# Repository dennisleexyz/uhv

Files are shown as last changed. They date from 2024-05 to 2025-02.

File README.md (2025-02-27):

# Unmanned Hybrid Vehicle (UHV)

California State Polytechnic University, Pomona (Cal Poly Pomona, CPP)\
College of Engineering\
Department of Electrical and Computer Engineering (ECE Department)

The Unmanned Hybrid Vehicle (UHV) combines a drone (Unmanned Aerial Vehicle; UAV) and rover (Unmanned Ground Vehicle; UGV). See the design review papers (PDF documents) for more information.

I unfortunately don't have any other files to share. If you're a team member, check/ask on Discord, and I encourage you to fork this repository to add stuff.

This was my undergraduate senior design project (under the name Flying UGV, or "Gliese-514b") with the Reconfigurable Space Computing Lab (RSCL) led by Professor Mohamed El-Hadedy Aly. We were selected by the [NASA MINDS](https://www.nasa.gov/learning-resources/minority-university-research-education-project/nasa-minds/) competition for Artemis mission research. I worked on it from Fall 2023 to Spring 2024 alongside the following team members:

- Manuel Tarula-Villareal
- Javier Eguia Chaire
- Ruben Torres Romero
- Justin Villamil

Students have rotated in and out as the project has continued since then.

If I'm not allowed to share anything here, contact me to have it taken down. All rights reserved.

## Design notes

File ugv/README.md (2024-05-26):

# UGV

Unmanned Ground Vehicle

## Hardware Setup

The UGV motors are controlled by an L298N Dual H-Bridge Driver connected to a Raspberry Pi.

Raspberry Pi is normally USB powered but can also be powered over GPIO power pins (+5V/Ground). This bypasses power protection circuitry for unstable supplies, but the Pixhawk provides regulated 5V pins. This provides enough power for headless operation. In the event that a monitor is needed, it will draw too much power and shut off; unplug the +5V supply pin and plug in USB power (don't connect both at the same time). If using the signals, ensure that the ground pin remains connected to the Pixhawk in order to provide a common ground with the L298N or else they will not work.

We should measure the current draw by the Pi from the Pixhawk under load to see what the maximum is before shut off. In the future we should try tapping 5V directly from the power module to see if this will allow for more current.

Pi 4 and up are annoying because of the switch to mini-HDMI port, for which cables are not as readily available. For this reason, consider going back to Pi 3 if the extra compute power is not needed.

### Wiring Diagram

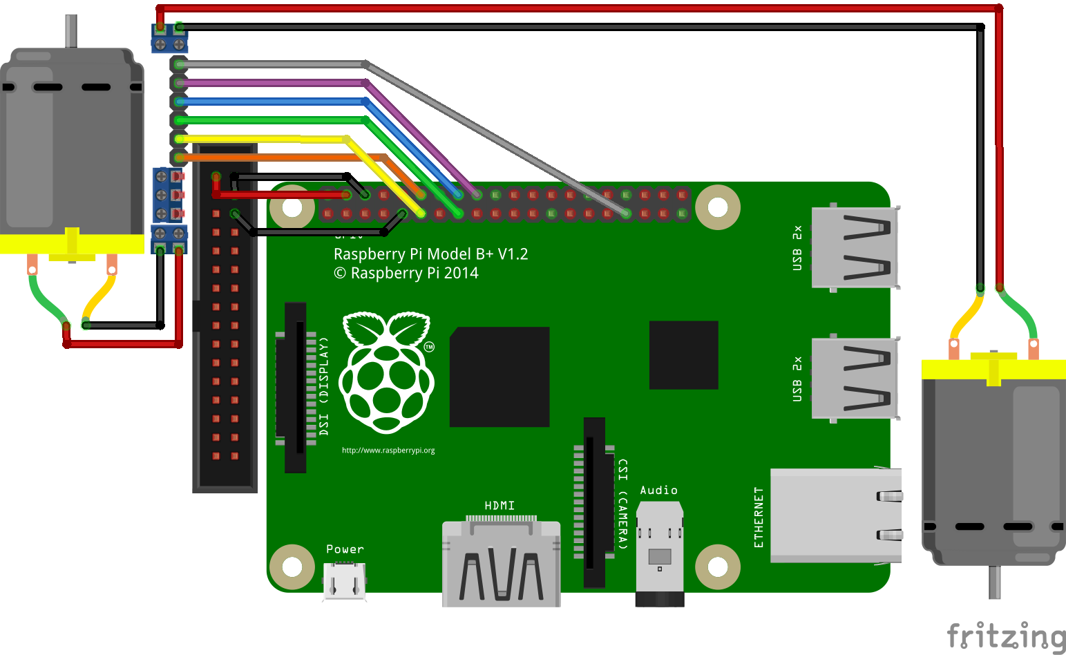
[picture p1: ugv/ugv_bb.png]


The wiring diagram was made in [Fritzing](https://fritzing.org/). The source file is included in this repository so you can edit it if needed. Fritzing will also show you what the pins are on the Pi when you hover over them in the program.

Pi GPIO pin reference: https://pinout.xyz/

Different GPIO pins can be used; just adjust the code accordingly.

The top row of pins on the Pixhawk is ground; the middle row is 5V. See https://ardupilot.org/copter/docs/common-pixhawk-overview.html

## Software Setup

For wireless communication we connect to the Pi over eduroam using SSH.

The password is not your normal password that you use to log in to your MyCPP portal. Rather it is a separate network password that you can set by going to https://apps.cpp.edu/

To enable incoming SSH connections on the Pi, open Preferences > Raspberry Pi Configuration. Go to the Interfaces tab. Ensure the SSH radio button is set to Enable and click OK.

On the Pi, run
```sh
hostname -I
```
to determine its IP address, which looks something like this.
```
10.110.xxx.xxx
```
Use this for the following steps.

On your computer, run
```sh
ssh pi@10.110.xxx.xxx
```
to connect to the Pi.

Get the code on the Pi, either by cloning this repository
```sh
git clone https://github.com/dennisleexyz/uhv
cd uhv/ugv
```
or just copying it over from your local machine
```sh
scp ugv.py pi@10.110.xxx.xxx:
```

Run it
```sh
python3 ugv.py
```

`WASD` is Up/Left/Down/Right, `J` and `K` to lower and raise PWM duty cycle respectively to the motors. Warning: duty cycle starts at full speed by default.

The IP address is not stable, it is subject to change periodically. Expect that you will need to re-acquire it.

### Raspbian

Raspbian's UI for connecting to a network does not support WPA Enterprise networks, e.g. eduroam. We can install NetworkManager and use that instead, disabling the default.

```sh
sudo apt install network-manager{,-gnome}
sudo systemctl disable --now dhcpcd
sudo systemctl enable --now network-manager
setsid nm-applet
```

See https://raspberrypi.stackexchange.com/a/119653

# Troubleshooting

The battery connector may need to be replaced e.g. in the event that the battery is plugged in backwards (reverse polarity). When replacing the connector, care will need to be taken to ensure that the two terminals do not short. Use the yellow XT90 connectors, which are on all of the batteries in the lab and not prone to being plugged in backwards like the blue connectors.

Cut the wire directly underneath just one of the connector terminals, using a sufficiently small wire cutter to prevent sparking with the other terminal. Place the connector sleeve on the wire. Strip and solder the wire to the correct solder cup (ensure the same polarity) on the new connector. Ensure continuity between the inside connector terminal and the solder (not the cup) using a multimeter. Insulate the new solder joint with Kapton tape. Now cut the wire directly underneath the old connector on the other terminal. Ensure the connector sleeve is on both wires before stripping and soldering the second wire, or you will have to desolder to put it on. After soldering the second wire and testing continuity, push the sleeve onto the new connector. You may have to remove the Kapton tape first.

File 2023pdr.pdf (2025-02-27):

## Development of Aerial Unmanned Ground Vehicles (UGV) to Enhance Support for the ARTEMIS Lunar Mission

## Gliese-514b

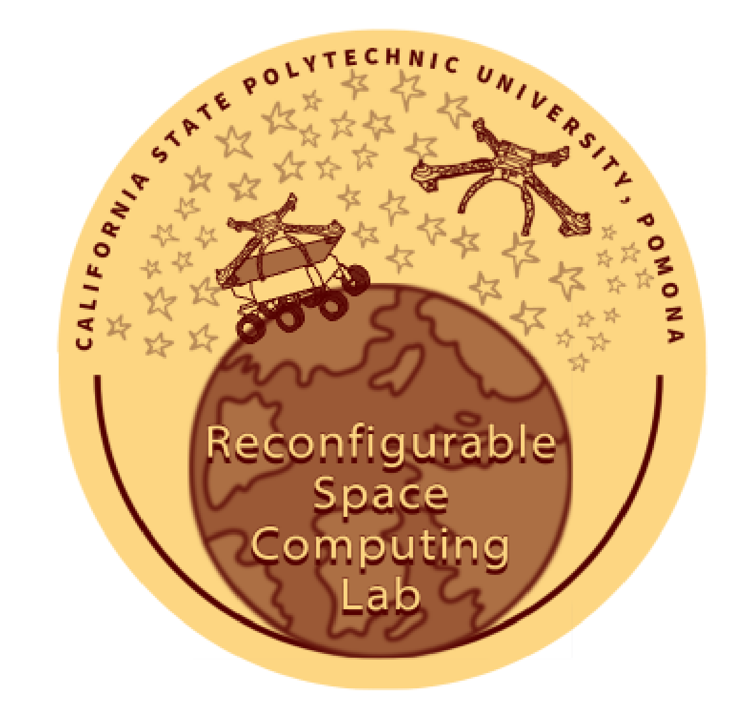
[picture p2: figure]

Team Members:
Ruben Torres Romero, Manuel Tarula, Dennis Lee

Faculty Advisor: Professor: Mohamed El-Hadedy Aly

Email:mealy@cpp.edu

California State Polytechnic University, Pomona Department of Electrical and Computer Engineering, College of Engineering

X

Signature of the sponsoring faculty advisor verifying that he has read and reviewed the paper prior to submission to NASA.

CONTENTS

I | Executive Summary | 1
II | Initial Project Schedule | 1
III | Budget Justification | 1
IV | Research | 2
I | Relevant Background | | 2
II | Problem Statement | | 3
a | Revolutionizing Lunar Exploration: Team Gliese-514b’s Innovative
Approach | | 3
III | Innovations | | 3
a | Technological Innovations: | | 4
IV | ARTEMIS Mission | | 4
V | Technical | 4
I | Gliese-514b team | | 4
II | Project Plan | | 4
III | Software Plan | | 5
Appendix A: Gantt Chart | 7
Appendix B: Cost Breakdown | 7

# Development of Aerial Unmanned Ground Vehicles (UGV) to Enhance Support for the ARTEMIS Lunar Mission

I. EXECUTIVE SUMMARY
Team Gliese-514b introduces a groundbreaking Aerial Unmanned Ground Vehicle (AUGV) tailored for the ARTEMIS Lunar Mission. Our AUGV is designed to navigate the moon’s challenging terrains, merging aerial and terrestrial capabilities for optimal exploration. Pioneering a unique approach, we utilize reconfigurable computing platforms to calculate real-time energy consumption during mode transitions. This innovative solution ensures efficient energy use, enabling extended operational duration. Our renewed team composition, with diverse expertise, commits to bridging the technological gaps in lunar exploration, enhancing mission success potential, and charting a path for future interplanetary endeavors.

II. INITIAL PROJECT SCHEDULE
The Gantt chart presented in Appendix A offers a comprehensive overview of Gliese-514b’s meticulous project plan. The endeavor unfolds through three distinct phases, each marked by specific objectives and actions, meticulously structured for success:
- Phase 1: Research and Design In the initial phase, Gliese-514b embarks on an exhaustive exploration of mechanical design possibilities for the Flying UGV. This encompasses the creation of a detailed 3D model and the meticulous specification of essential components crucial for enabling both ground and aerial navigation. Simultaneously, a dedicated software development effort is set in motion to orchestrate the seamless orchestration of sensors and flight control systems.
- Phase 2: Assembly and Hardware Implementation The second phase witnesses Gliese-514b’s procurement efforts as they acquire every essential hardware component required for the assembly of the Flying UGV. Furthermore, this stage is marked by the intricate integration of various peripherals, harmoniously weaving them into the fabric of the UGV. A symphony of components comes to life as they are meticulously assembled and brought together.
- Phase 3: Testing and Implementation The final leg of the journey ushers in rigorous testing and implementation efforts. Gliese-514b meticulously subjects the assembled UGV to a battery of tests, scrutinizing its performance in both ground and flight modes. This phase serves as the crucible in which the Flying UGV’s capabilities are benchmarked, and refinements to the design are deftly implemented. It is the culmination of the team’s efforts, where the vision becomes a tangible reality. In these meticulously structured phases, Gliese-514b’s mission unfolds, propelled by dedication, precision, and an unwavering commitment to achieving its objectives.

III. BUDGET JUSTIFICATION

Appendix B provides a comprehensive breakdown of the materials and associated costs crucial for the realization of the Gliese-514b project. Each component and resource has been carefully selected to align with the project’s objectives, with an unwavering focus on efficiency and functionality.
The backbone of the Gliese-514b Flying UGV is its chassis, a critical component known for its remarkable strength, durability, and ease of fabrication. To this end, the chassis will be precisioncut from acrylic, ensuring a solid foundation for the UGV’s operations. Additionally, PLA filament will be skillfully employed to craft miscellaneous parts, enhancing the overall versatility and functionality of the Flying UGV.
Powering the UGV’s electrical systems will be battery units, affording the flexibility and mobility necessary for its mission. The central nervous system of the UGV comprises a Raspberry Pi, complemented by a Navio2 HAT. An intricate network of wires serves as the neural pathways connecting various components, facilitating seamless coordination and control.
The UGV’s locomotion is driven by a combination of four propellers and four wheels, each meticulously powered by dedicated motors. Two sets of 4 in 1 ESCs [1] provide the precise motor control required for optimal performance. Notably, the choice of motors for the wheels prioritizes higher torque and lower RPM, a deliberate decision to meet the UGV’s specific operational demands. Communication lies at the heart of the Gliese-514b project, necessitating the integration of a telemetry radio system to maintain a robust connection between the UGV and the ground control station.
Navigation | and | mapping | capabilities | are
paramount | for | the | UGV, | achieved | through
the inclusion of camera sensors [2] and a LiDAR sensor. While the Raspberry Pi inherently supports a single camera, Gliese-514b’s multifaceted approach mandates the use of a camera port multiplexer to transcend this limitation. Furthermore, high-power infrared LEDs are enlisted to enhance visibility in low-light environments, ensuring the UGV’s adaptability to various scenarios.
Lastly, an SSD storage solution accommodates the substantial volume of data generated by the Li-DAR sensor and multiple cameras [3]. This storage capacity ensures that critical data can be efficiently captured, stored, and utilized throughout the mission.
In sum, Gliese-514b’s material and cost allocation exemplify a meticulous selection process, guided by the team’s unwavering commitment to achieving project success through precision, efficiency, and optimal functionality.

IV. RESEARCH

A. Relevant Background
The Artemis mission unfolds in three distinct phases, each marking a significant milestone in humanity’s journey into space. Artemis I marked a pivotal moment with NASA successfully launching the Orion Spacecraft. This mission also involved the comprehensive development and testing of essential elements such as the space launch system rocket, the human landing system, and the exploration ground systems. Rigorous testing was conducted to finetune these critical utilities, ensuring their readiness for the challenges that lie ahead.
Artemis II stands as the next ambitious endeavor, set to send astronauts to the Moon in 2025, with the ultimate goal of establishing a lunar base. This mission aims to further test the endurance of astronauts, the reliability of the Orion Spacecraft, the space launch system rocket, the human landing system, and the exploration ground systems. It’s a critical step toward building operational confidence and preparing for Artemis III.
Artemis III represents the pinnacle of ambition, envisioning the establishment of a lunar base that will serve as a launchpad for Mars exploration. The Moon will become a hub for scientific research and technological advancement, acting as a stepping stone toward the grander goal of Mars exploration. This mission heralds an era where a minimal human presence interacts with advanced technology, all for the betterment of humanity.
However, lunar exploration presents formidable challenges, particularly in the challenging terrain of the Moon’s far side. Traditional rovers struggle to navigate uneven and rugged landscapes, highlighting a technological gap in our ability to explore efficiently. The need for swift and adaptable aerial and terrestrial navigation in these harsh conditions is evident, promising to revolutionize lunar exploration and enhance data collection.
In response to this challenge, team Gliese-514b rises to the occasion with a groundbreaking proposal—an innovative Aerial Unmanned Ground Vehicle (AUGV). This visionary creation combines the strengths of flight-capable drones and ground-based rovers, offering unparalleled agility to soar over treacherous terrains and the stability to maneuver on the ground when required.
Gliese-514b’s AUGV is set to redefine lunar exploration, bridging the gap between aerial and terrestrial capabilities. It promises to revolutionize the efficiency, range, and speed of lunar missions, enabling comprehensive data collection and significantly increasing the probability of mission success. With this innovative solution, the team paves the way for a new era of lunar exploration, unlocking the mysteries of our celestial neighbor and propelling humanity toward the stars.

B. Problem Statement

The Gliese-514b team is tackling a pressing challenge in lunar exploration—bridging the technological gap for more efficient and adaptable surface exploration. Currently, the Artemis program relies heavily on orbital surveys, providing only a limited understanding of lunar landing sites. The moon’s rugged terrain, marked by craters and steep slopes, presents significant challenges for traditional Unmanned Ground Vehicles (UGVs), hindering efficient surface exploration. To overcome these obstacles and enhance mission planning, the team proposes the integration of a Flying Unmanned Ground Vehicle (AUGV) with the capability to conduct detailed lunar surface surveys.
This innovative approach aims to revolutionize lunar exploration by providing a versatile solution that seamlessly transitions between aerial and terrestrial modes. The AUGV’s robust propulsion system, combined with specialized wheel or track systems, enables it to , conserving energy and overcoming large obstacles. Furthermore, the team’s focus on energy consumption calculation using reconfigurable computing platforms ensures real-time feedback on the AUGV’s energy status, contributing to longer mission durations and enhanced exploration capabilities.
1) Revolutionizing Lunar Exploration: Team Gliese-514b’s Innovative Approach: Team Gliese-514b distinguishes itself through its multidisciplinary expertise and holistic project approach. Bringing together diverse skills in aerospace dynamics, robotics, computational intelligence, and reconfigurable computing platforms, the team ensures a comprehensive solution to the problem. Their emphasis on energy consumption calculation using reconfigurable computing platforms not only benefits the current project but also paves the way for adaptable, energy-efficient systems in future lunar missions.
In conclusion, the Aerial-Terrestrial UGV proposed by team Gliese-514b addresses a critical technological gap in lunar exploration [4]. By merging aerial and terrestrial navigation capabilities, their innovative solution promises to navigate the challenging lunar terrain efficiently and adaptable. This contribution has the potential to significantly enhance the success of future lunar missions within the NASA Artemis program, optimizing unmanned lunar exploration for strategic mission planning and safe lunar surface activities.
C. Innovations

The Gliese-514b project is dedicated to the creation of a low-power, low-latency Flying Unmanned Ground Vehicle (UGV) tailored for versatile applications, with a particular focus on its role during the Artemis III mission phase. Operating under the umbrella of the Reconfigurable Space Computing Laboratory at CPP, Gliese-514b is an integral part of a pioneering initiative aimed at developing cuttingedge technology to establish a collaborative robotic environment as shown in Figure 1. This environment facilitates the seamless coordination of heterogeneous robotic elements for deep-space missions, effectively executing tasks and transmitting critical data to Earth for further analysis, as illustrated in Figure 1.
The project’s core objectives revolve around the comprehensive development of both software and hardware platforms, culminating in the creation of a robust and fully integrated system optimized for lunar and Mars exploration. The overarching vision envisions the deployment of this innovative device within a collaborative robotics framework, significantly enhancing the efficiency and adaptability of exploration endeavors.
At the heart of this endeavor lies a resilient propulsion system capable of facilitating smooth transitions between flying and driving modes. This pioneering propulsion technology not only promises to deliver higher-resolution scans of the lunar surface but also positions the Flying UGV as an indispensable asset for lunar and Martian exploration missions. Furthermore, the incorporation of LiDAR sensors enhances the vehicle’s navigational capabilities, allowing real-time mode adjustments based on the prevailing environmental conditions.
In tandem with the adaptable propulsion system, the Gliese-514b team is actively engaged in the development of a specialized algorithm, leveraging the potential of reconfigurable computing platforms. This algorithm serves a critical role in meticulously calculating energy consumption during transitions between flying and driving modes, providing real-time energy analysis crucial for mission planning. This ensures that the Flying UGV operates efficiently within predefined energy thresholds, opti-

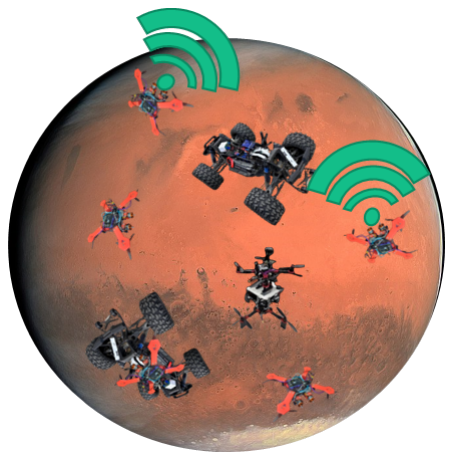
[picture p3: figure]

Fig. 1: Collaborative Robotic Environment featuring the Gliese-514b Flying UGV

mizing resource utilization in the demanding lunar environment.
1) Technological Innovations::
- Flying-to-Driving Transition: The AUGV boasts a robust propulsion system capable of stable hovering and dynamic flying maneuvers. Coupled with specialized wheel or track systems, this system enables seamless transitions between flight and ground modes. Such versatility ensures that the AUGV can surmount obstacles by flying and continuing its journey on the ground, optimizing energy conservation.
- Energy Consumption Calculation: Efficient energy utilization is a fundamental challenge for multi-modal vehicles. The Gliese-514b project addresses this challenge by developing a specialized algorithm on a reconfigurable computing platform to accurately compute power consumption during transitions between flying and driving modes. Real-time energy analysis aids in mission planning, ensuring that the AUGV always operates within safe energy thresholds.
- Terrain Adaptability: To navigate the capricious lunar terrain, the AUGV incorporates advanced terrain sensing capabilities. These sensors provide real-time feedback to the system, enabling it to determine the optimal mode of movement, whether flight or ground-based, depending on the prevailing environmental conditions.
D. ARTEMIS Mission
Team Gliese-514b’s Aerial Unmanned Ground Vehicle (AUGV) plays a pivotal role in bolstering

NASA’s ARTEMIS Lunar Mission by significantly enhancing navigation capabilities across the moon’s formidable terrains. By seamlessly integrating both aerial and terrestrial functionalities, the AUGV enables efficient and comprehensive exploration, particularly on the rugged and challenging dark side of the moon. Moreover, the Gliese-514b Flying UGV offers invaluable support to the Artemis Mission through its advanced navigation and terrain mapping capabilities. Equipped with LiDAR sensors, it adeptly navigates the unpredictable lunar terrain, effortlessly switching between ground and flight modes, ensuring unparalleled mobility, and generating detailed maps of the rugged lunar landscape. This multifaceted approach empowers the mission with enhanced adaptability and data collection capabilities.

V. TECHNICAL
A. Gliese-514b team

The current project is centered on setting up equipment on a flexible resin-printed chassis, aiming to enhance computational capabilities with a customized flight controller based on the F’ JPL/NASA flight software. This setup includes a thermal camera for chip monitoring. Future work will focus on predicting chip failure due to intensive activities.

B. Project Plan

To initiate the Flying UGV project, the primary step involves conceiving a lightweight chassis design with a minimal footprint, as illustrated in Figure 3. This updated design seamlessly accommodates all essential components required for autonomous flight, driving, and exploration, representing an improvement over the previous design showcased in Figure 2. The new design features a more robustly engineered, lightweight chassis, which will be fabricated using either laser-cut acrylic or light resin [5], with ongoing investigations to determine the ideal material for the final prototype. Once the dimensions and optimal arrangement of these components are determined, the subsequent phase involves the development of a comprehensive 3D CAD model. The chassis, as depicted in Figure 2, will be crafted from acrylic and complemented with 3D printed components. Following the fabrication of

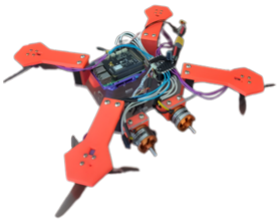
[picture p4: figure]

Fig. 2: Flying UGV Prototype of Past Design

these components, the assembly of the Flying UGV can commence.
Simultaneously, while finalizing the physical design, the software aspect of the project will be actively worked on. Team Gliese-514b will begin establishing communication protocols with the various cameras, sensors, and ESCs to ensure seamless integration and operation.
Upon the successful assembly and the establishment of seamless communication with its components, Gliese-514b will proceed to conduct a series of rigorous tests on the Flying UGV. The testing phase will commence with remote operation trials, subsequently followed by autonomous navigation testing in both ground and flight modes.
C. Software Plan
The software stack chosen for this project encompasses several key components to enable the Flying UGV’s comprehensive exploration and mapping capabilities. It includes the PiCamera app for PiCameras, DroidCam for the potential addition of another camera through a smartphone, and LidarView to process data from the LiDAR sensor. The aim is to leverage multiple image and videoproducing devices to conduct thorough scans and assess the lunar or Martian surroundings, ultimately creating detailed maps. Additionally, the LiDAR and camera inputs will facilitate the extraction of positioning information, enabling the system to calculate potential obstacles and its relative position within the observed area. The software will play

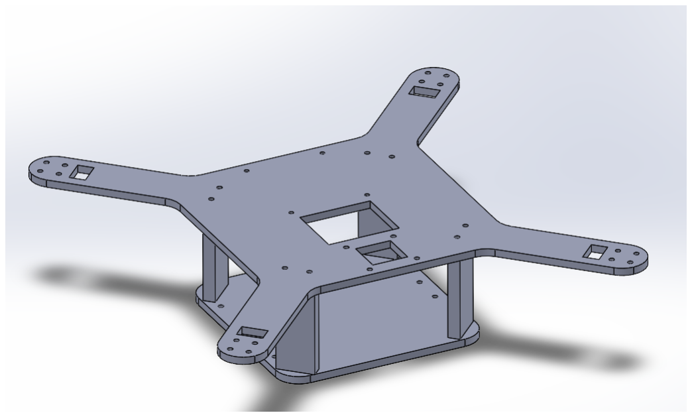
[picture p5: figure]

Fig. 3: CAD of Current Drone

a crucial role in associating the surroundings with precise coordinate references, enhancing the overall mapping process.
To enhance the Flying UGV’s ability to differentiate between various materials and objects found on the Moon, computer vision capabilities will be integrated. This involves training a YOLOv8 model on cloud resources to enable the identification of different vehicles and objects [6]. Initial simulations will be conducted on Earth-based devices and objects to validate the proof of concept. The long-term vision is to train and deploy a model within the UGV itself, allowing it to avoid collisions with counterparts during missions. Additionally, teleoperation features will be added to the Flying UGV, utilizing the MediaPipe Library and potentially YOLOv8. Hand gestures will serve as the means to convey start and stop commands to the UGV, enhancing its control and interaction capabilities.
Following the creation and full integration of the software stack, Gliese-514b will proceed with rigorous testing procedures. Successful tests will pave the way for the software’s utilization of the actual drones. This entails the establishment of boundary conditions, such as ensuring the Flying UGV maintains a safe distance of 1 meter from obstacles. The computer vision aspect will enable task assignment and control, making the project safe and collision-free. Moreover, it will provide astronauts with a means to assign tasks to the UGV, fostering a collaborative robotic environment where the device can receive instructions through gestures or local networks from other similar vehicles.

REFERENCES
[1] B.-S. Jun, Y.-S. Kook, J.-S. Park, and C.-Y. Won, “A development of electronic speed control (esc) for pmsms driving used in drone,” in 2018 IEEE International Power Electronics and Application Conference and Exposition (PEAC), 2018, pp. 1–4. DOI

: 10.1109/PEAC.
2018.8590355 (https://doi.org/10.1109/PEAC.2018.8590355)
[2] A. A. Sarawade and N. N. Charniya, “Infrared thermography and its applications: A review,” in 2018 3rd International Conference on Communication and Electronics Systems (ICCES), 2018, pp. 280–285. DOI
: 10 . 1109 / CESYS .
2018.8723875 (https://doi.org/10.1109/CESYS.2018.8723875)
[3] Y. J. Hao, L. K. Teck, C. Y. Xiang, E. Jeevanraj, and S. Srigrarom, “Fast drone detection using ssd and yolov3,” in 2021 21st International Conference on Control, Automation and Systems (ICCAS), 2021, pp. 1172–1179. DOI

:
10.23919/ICCAS52745.2021.9650015 (https://doi.org/10.23919/ICCAS52745.2021.9650015)
[4] L. Deng, B. Yang, X. Dong, et al., “Self-spin enabled docking and detaching of a uav-ugv system for aerial-terrestrial amphibious and independent locomotion,” IEEE Robotics and Automation Letters, vol. 8, no. 5, pp. 2454– 2461, 2023. DOI

: 10.1109/LRA.2023.3254445 (https://doi.org/10.1109/LRA.2023.3254445) .
[5] P. Gupta, M. Bhat, V. Khamkar, G. Tandel, and
G. Salunkhe, “Designing of cost effective resin 3d printer using uv led,” in 2020 International Conference on Convergence to Digital World
- Quo Vadis (ICCDW), 2020, pp. 1–4. DOI :
10.1109/ICCDW45521.2020.9318691 (https://doi.org/10.1109/ICCDW45521.2020.9318691)
[6] J.-H. Kim, N. Kim, and C. S. Won, “Highspeed drone detection based on yolo-v8,” in ICASSP 2023 - 2023 IEEE International Conference on Acoustics, Speech and Signal Processing (ICASSP), 2023, pp. 1–2. DOI: 10 . 1109/ICASSP49357.2023.10095516 (https://doi.org/10.1109/ICASSP49357.2023.10095516)

APPENDIX A
GANTT CHART

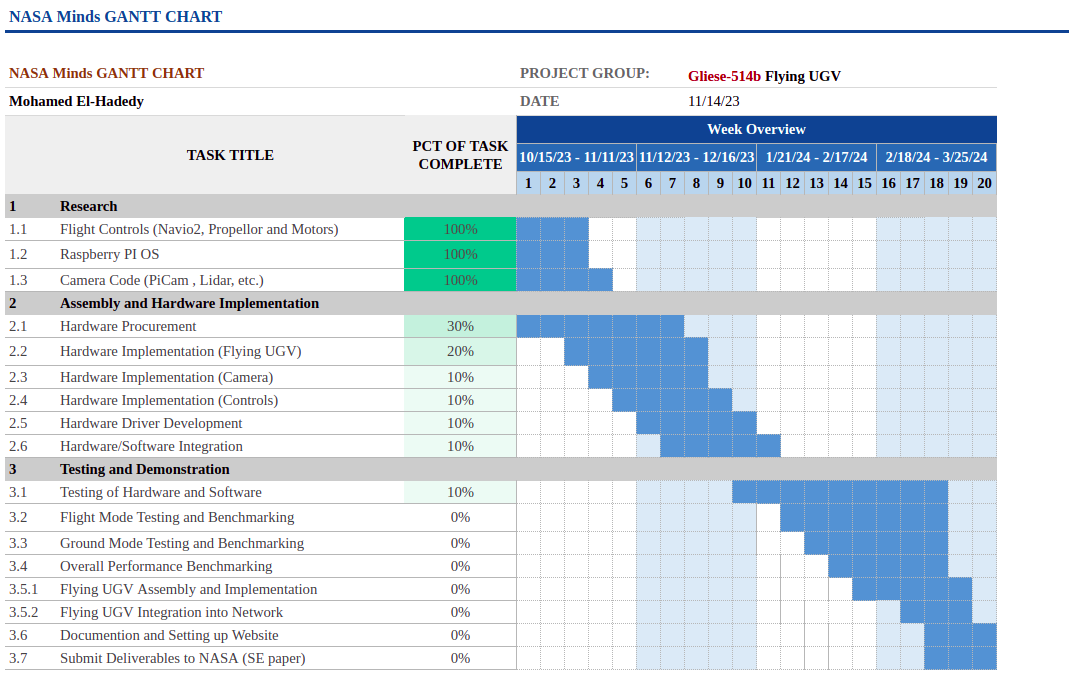
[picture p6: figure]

Gantt Chart of Scheduling

APPENDIX B
COST BREAKDOWN
Name | Cost ($) | Amount | Total Cost ($)
Acrylic sheets | 32.00 | 2 | 64.00
Raspberry Pi | 79.81 | 1 | 79.81
Navio2 Flight Controller | 100.00 | 1 | 100.00
Propeller Motors | 24.00 | 4 | 96.00
Wheel Motors | 34.00 | 4 | 136
ESC | 100.00 | 2 | 200.00
4s Battery | 80.00 | 1 | 80.00
Telemetry Radio | 90.00 | 1 | 90.00
Camera | 59.99 | 4 | 239.96
PLA Filament | 25.00 | 2 | 50.00
LiDAR Sensor | 54.00 | 1 | 54.00
Wheels | 8.25 | 4 | 33.00
Propellers | 10.00 | 4 | 40.00
Multicamera adapter | 29.99 | 1 | 29.99
Jumper wires | 19.98 | 1 | 19.98
Infrared LEDs | 8.99 | 4 | 35.96
2TB SSD | 159.99 | 1 | 159.99
Total | | | $1,508.69

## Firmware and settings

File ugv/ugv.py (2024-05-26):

#!/usr/bin/env python3

import RPi.GPIO as GPIO
from sshkeyboard import listen_keyboard
import time

# Setup
GPIO.setmode(GPIO.BCM)
GPIO.setwarnings(False)

# Motor A
ena = 18  # Motor A speed control
motorA_pin1 = 17
motorA_pin2 = 22

# Motor B
enb = 13  # Motor B speed control
motorB_pin1 = 24
motorB_pin2 = 23

# Setup the motor pins as outputs
GPIO.setup(ena, GPIO.OUT)
GPIO.setup(enb, GPIO.OUT)
GPIO.setup(motorA_pin1, GPIO.OUT)
GPIO.setup(motorA_pin2, GPIO.OUT)
GPIO.setup(motorB_pin1, GPIO.OUT)
GPIO.setup(motorB_pin2, GPIO.OUT)

# Initialize PWM
pwmA = GPIO.PWM(ena, 1000)  # Initialize PWM on ena 1000Hz frequency
pwmB = GPIO.PWM(enb, 1000)  # Initialize PWM on enb 1000Hz frequency

# Start PWM with a defined speed
speed = 100
pwmA.start(speed)  # Adjust this value between 0-100 to control speed
pwmB.start(speed)  # Adjust this value between 0-100 to control speed

def motors_forward():
    GPIO.output(motorA_pin1, GPIO.LOW)
    GPIO.output(motorA_pin2, GPIO.HIGH)
    GPIO.output(motorB_pin1, GPIO.LOW)
    GPIO.output(motorB_pin2, GPIO.HIGH)
    print("Moving forward")

def motors_backward():
    GPIO.output(motorA_pin1, GPIO.HIGH)
    GPIO.output(motorA_pin2, GPIO.LOW)
    GPIO.output(motorB_pin1, GPIO.HIGH)
    GPIO.output(motorB_pin2, GPIO.LOW)
    print("Moving backward")
    
def motors_left():
    GPIO.output(motorA_pin1, GPIO.HIGH)
    GPIO.output(motorA_pin2, GPIO.LOW)
    GPIO.output(motorB_pin1, GPIO.LOW)
    GPIO.output(motorB_pin2, GPIO.HIGH)
    print("Moving left");
    
def motors_right():
    GPIO.output(motorA_pin1, GPIO.LOW)
    GPIO.output(motorA_pin2, GPIO.HIGH)
    GPIO.output(motorB_pin1, GPIO.HIGH)
    GPIO.output(motorB_pin2, GPIO.LOW)
    print("Moving right");

def stop_motors():
    GPIO.output(motorA_pin1, GPIO.LOW)
    GPIO.output(motorA_pin2, GPIO.LOW)
    GPIO.output(motorB_pin1, GPIO.LOW)
    GPIO.output(motorB_pin2, GPIO.LOW)
    print("Motors stopped")

def on_press(key):
    global speed
    try:
        if key == 'w':  # Forward
            motors_forward()
        elif key == 's':  # Backward
            motors_backward()
        elif key =='a':
            motors_left();
        elif key == 'd':
            motors_right();
        elif key == 'j':  # Backward
            speed -= 10
            if speed <= 10:
                    speed = 0
            print(f'PWM = {speed}')
        elif key == 'k':  # Backward
            speed += 10
            if speed >= 100:
                    speed = 100
            print(f'PWM = {speed}')
        pwmA.start(speed)
        pwmB.start(speed)

    except AttributeError:
        pass

def on_release(key):
    if key == 'esc':
        # Stop listener and PWM
        pwmA.stop()
        pwmB.stop()
        GPIO.cleanup()
        return False
    stop_motors()

# Collect events until released
with listen_keyboard(
        on_press=on_press,
        on_release=on_release) as listener:
    listener.join()
